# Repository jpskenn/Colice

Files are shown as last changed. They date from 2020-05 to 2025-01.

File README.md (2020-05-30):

# について / About
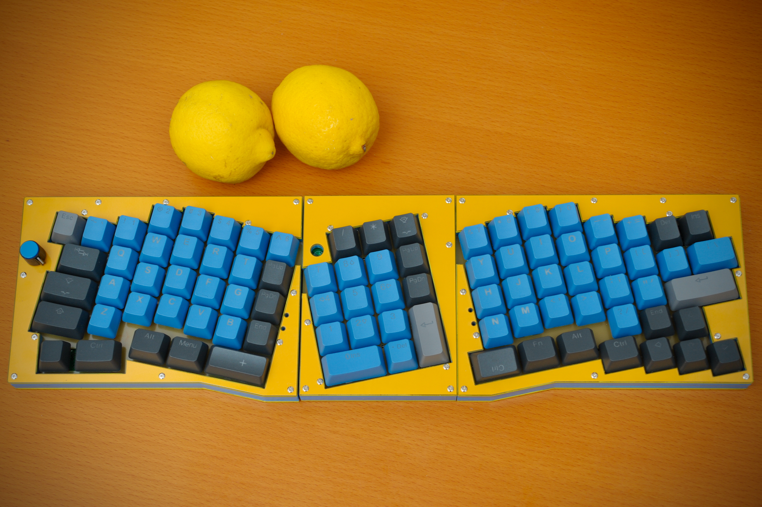
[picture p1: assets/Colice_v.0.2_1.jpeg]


Colice（コリス）

アリスのレイアウトに発想を得た、部位を組み合わせられるカラムスタッガー（列ずれ）配列の自作キーボード。
Self-made "Col"umnar stagger combinational moduler keyboard, inspired by Al"ice" layout.

## 特徴 / Features
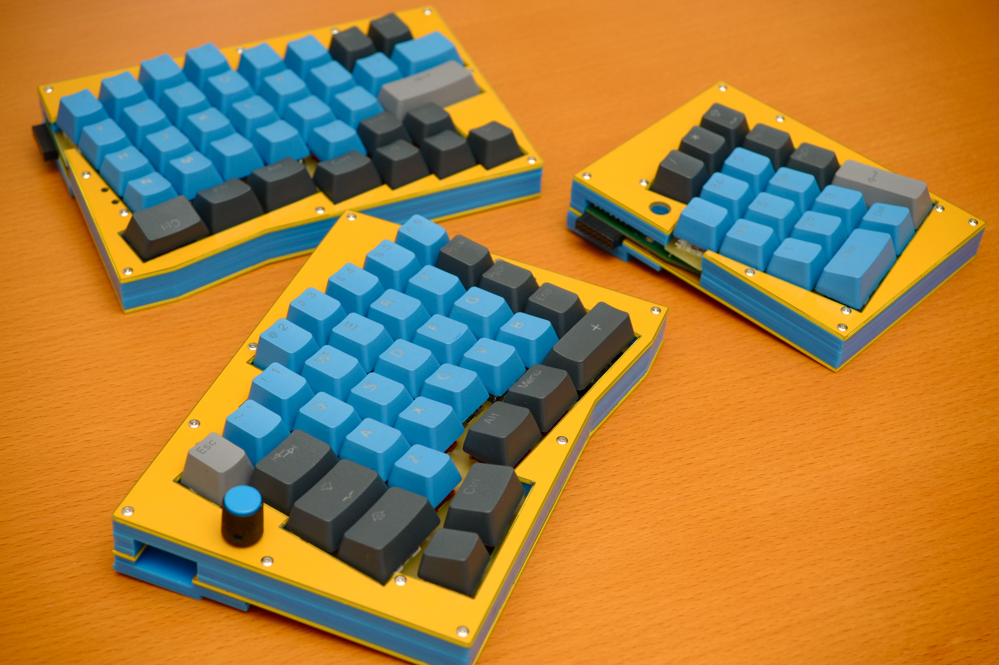
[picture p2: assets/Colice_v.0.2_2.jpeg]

- 一体型かつ分離型でレイアウトが変えられる
- トップマウント形式のケース
- ロータリーエンコーダを2個使用可能
- 総当たりマトリクス（2乗マトリクス）を採用
Pro Micro 1個で全てを制御
- I2C用のピンは未使用
- LEDチョットダケ光る
- 本来のケース外形はもっと丸い感じでかわいい
発注時ミスで、v.0.2は四角い外形になっている

## キー配列 / Layout

## 写真

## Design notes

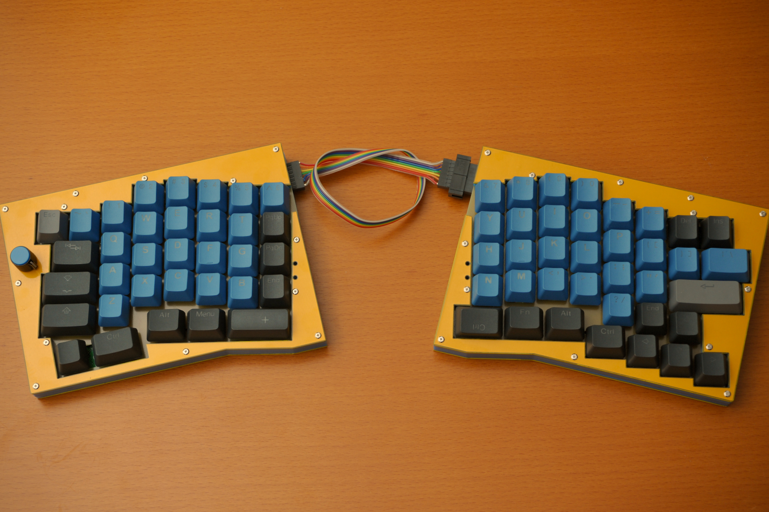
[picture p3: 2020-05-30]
assets/Colice_v.0.2_6.jpeg

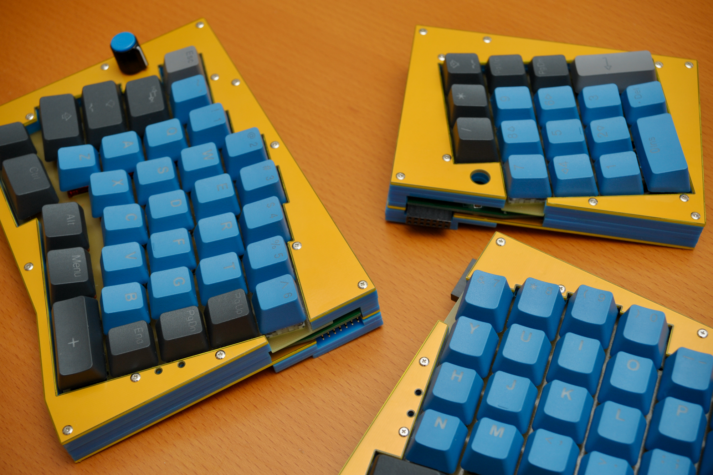
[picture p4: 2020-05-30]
assets/Colice_v.0.2_8.jpeg

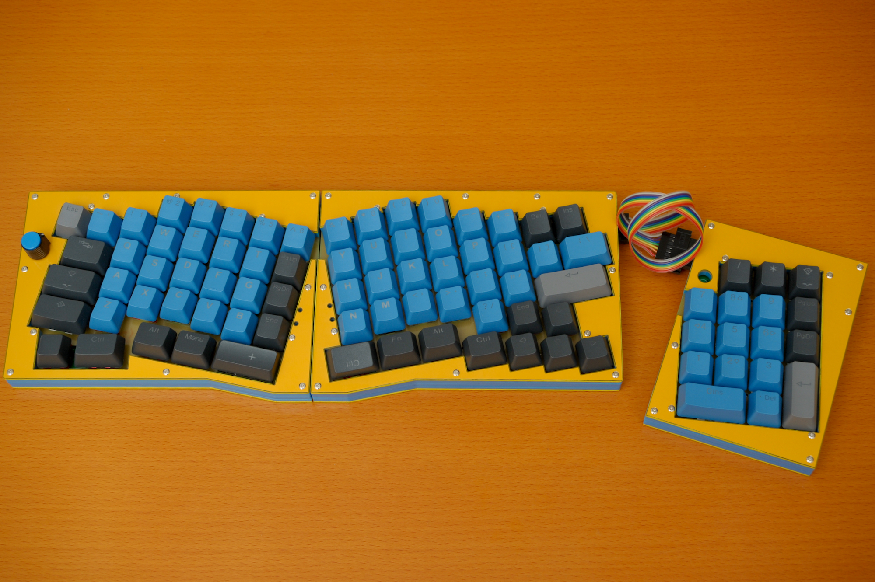
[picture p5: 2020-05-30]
assets/Colice_v.0.2_4.jpeg

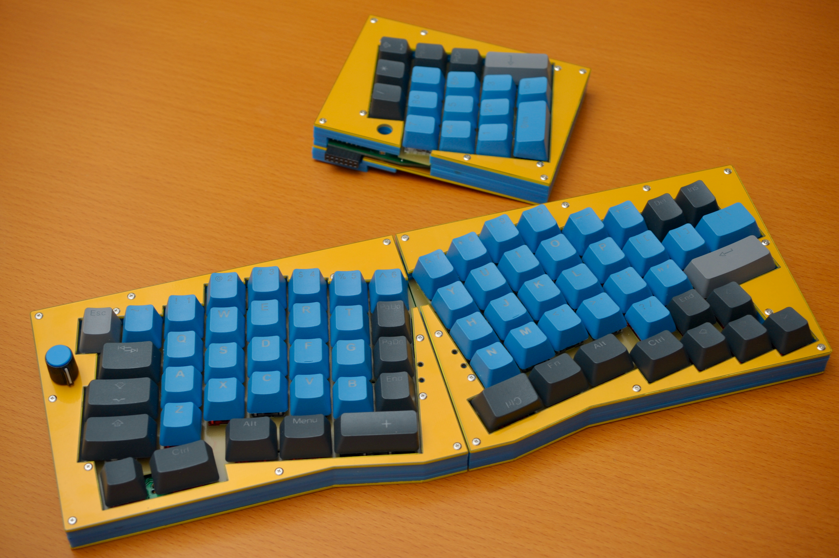
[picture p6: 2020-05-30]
assets/Colice_v.0.2_3.jpeg

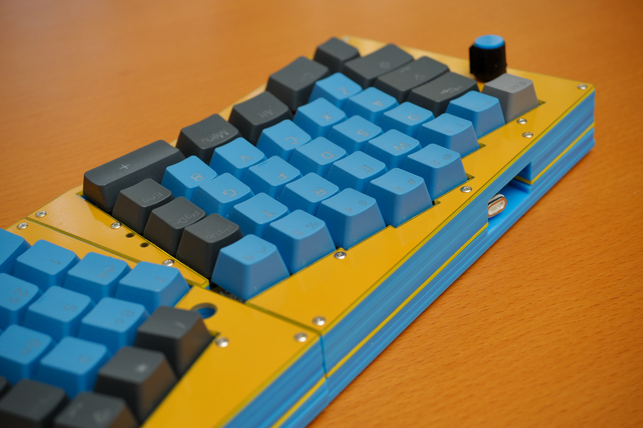
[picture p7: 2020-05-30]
assets/Colice_v.0.2_10.jpeg

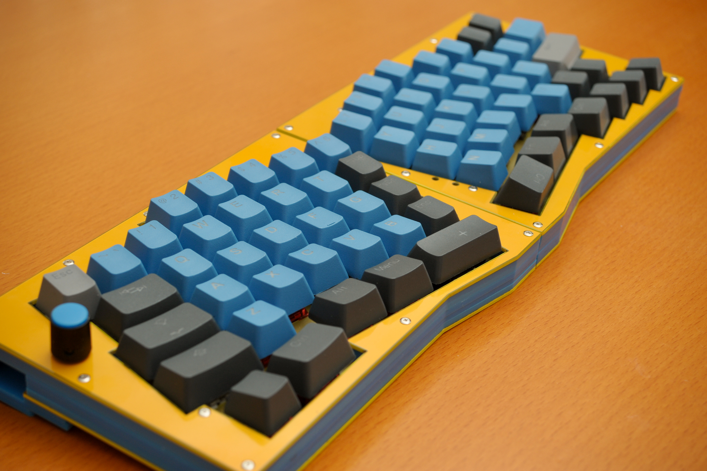
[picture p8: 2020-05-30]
assets/Colice_v.0.2_7.jpeg

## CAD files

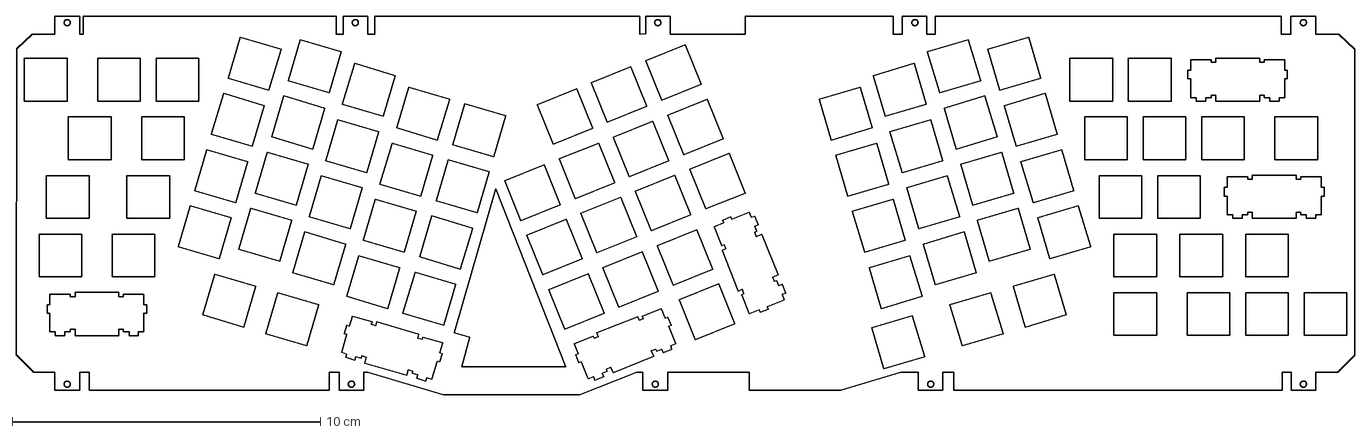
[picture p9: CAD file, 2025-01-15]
Case : Plate/キープレートPCB/Colice_20200219 v4.dxf
43.4 x 12.3 cm

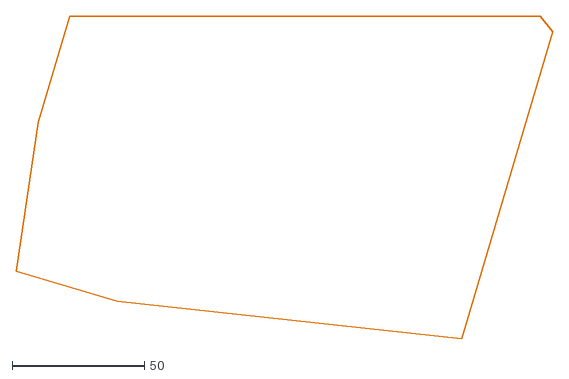
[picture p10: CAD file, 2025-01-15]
PCB/Colice_rev.0.1/board_outline.dxf
202.4 x 121.9

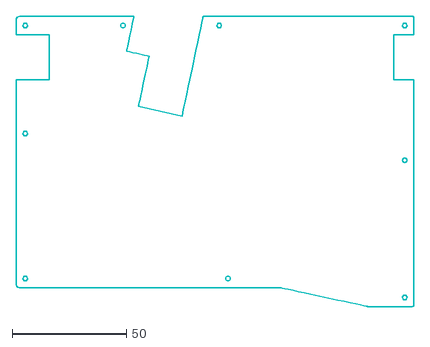
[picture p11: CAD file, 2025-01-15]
PCB_Bottom/v.0.2/LR-bottom-v02/outline.dxf
174.1 x 127.0

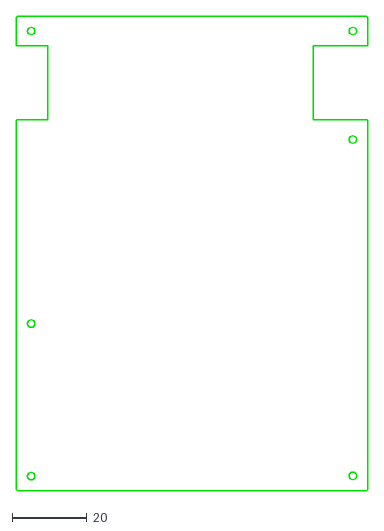
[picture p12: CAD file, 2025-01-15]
PCB_Bottom/v.0.2/N-bottom-v02/outline.dxf
94.1 x 127.0

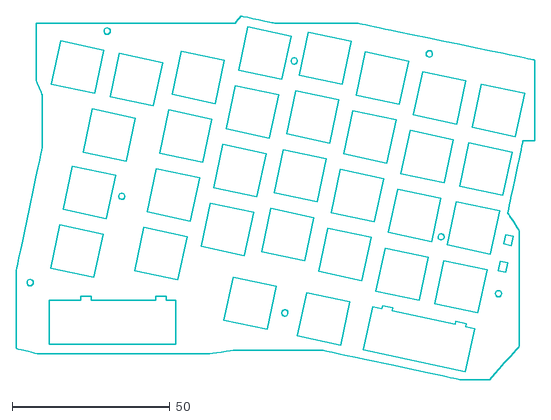
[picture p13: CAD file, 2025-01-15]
PCB_Keyplate/v.0.2/L-key-v02/outline.dxf
164.3 x 115.4

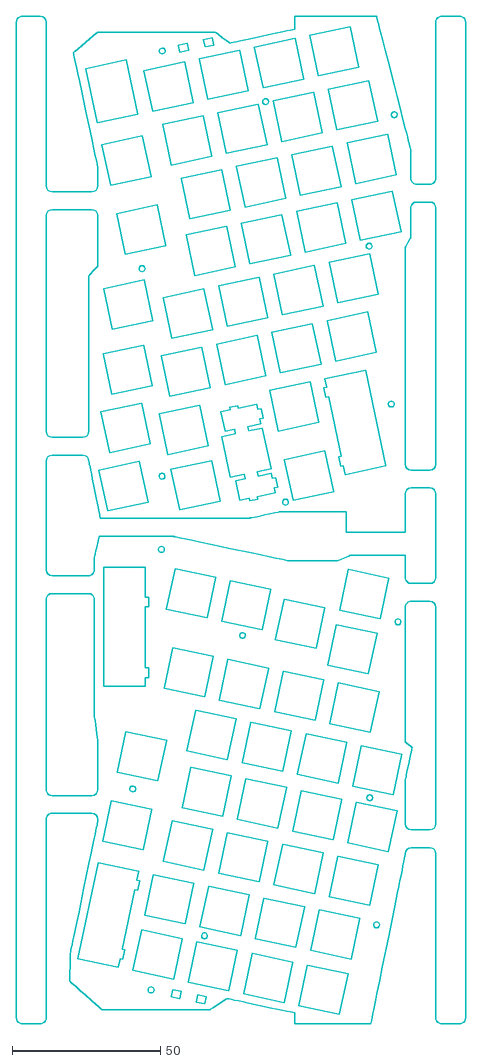
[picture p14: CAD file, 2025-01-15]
PCB_Keyplate/v.0.2/LR-key-v02/L+R_key.dxf
151.4 x 339.7

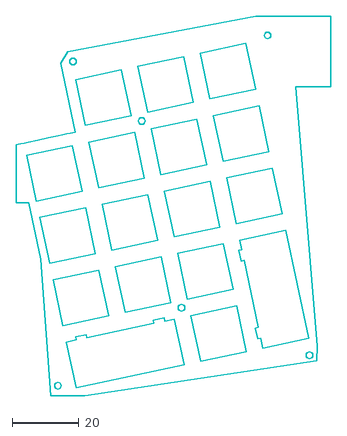
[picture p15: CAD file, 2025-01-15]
PCB_Keyplate/v.0.2/N-key-v02/outline.dxf
94.1 x 113.6

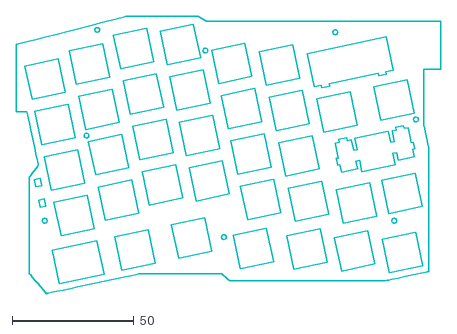
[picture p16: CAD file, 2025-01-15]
PCB_Keyplate/v.0.2/R-key-v02/outline.dxf
174.1 x 113.8

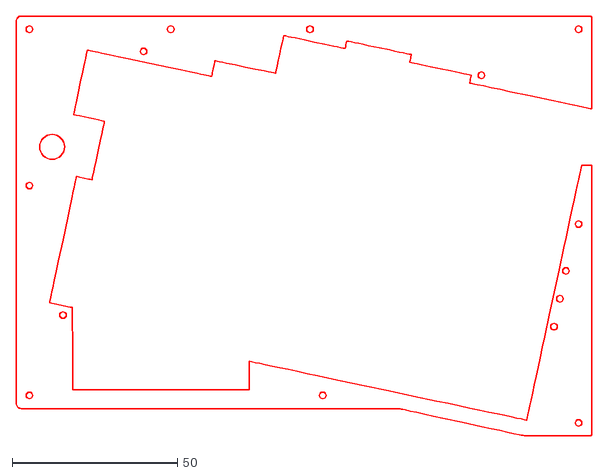
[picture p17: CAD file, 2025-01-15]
PCB_TopFrame/v.0.2/L-top-v02/outline.dxf
174.1 x 127.0

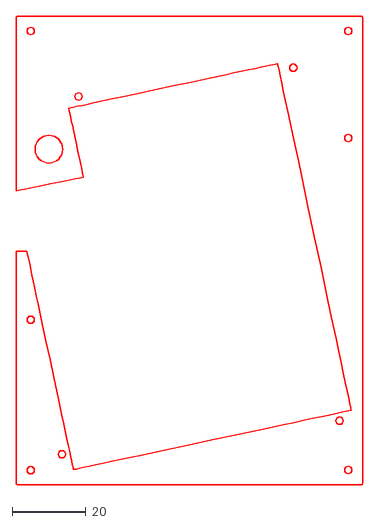
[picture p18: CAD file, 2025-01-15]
PCB_TopFrame/v.0.2/N-top-v02/outline.dxf
94.1 x 127.0

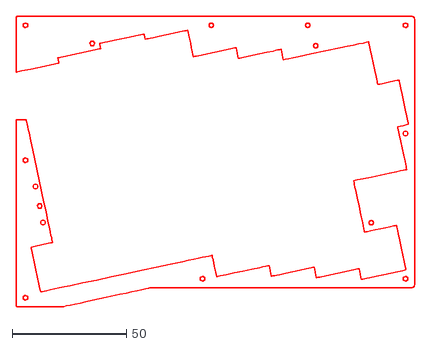
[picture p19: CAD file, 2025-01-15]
PCB_TopFrame/v.0.2/R-top-v02/outline.dxf
174.1 x 127.0

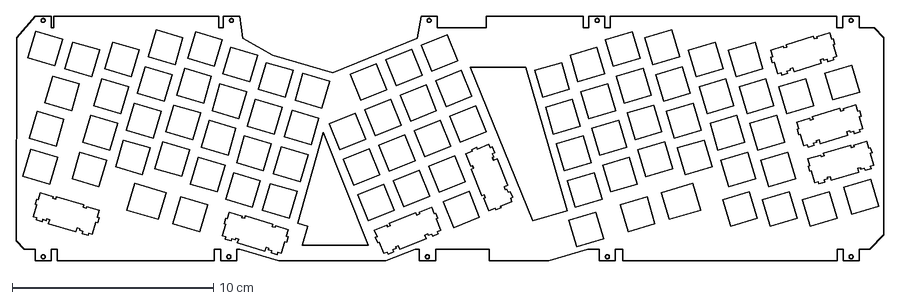
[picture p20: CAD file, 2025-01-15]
Case : Plate/キープレートPCB/Colice_PCB_Plate_v0.2 v1.dxf
43.1 x 12.1 cm

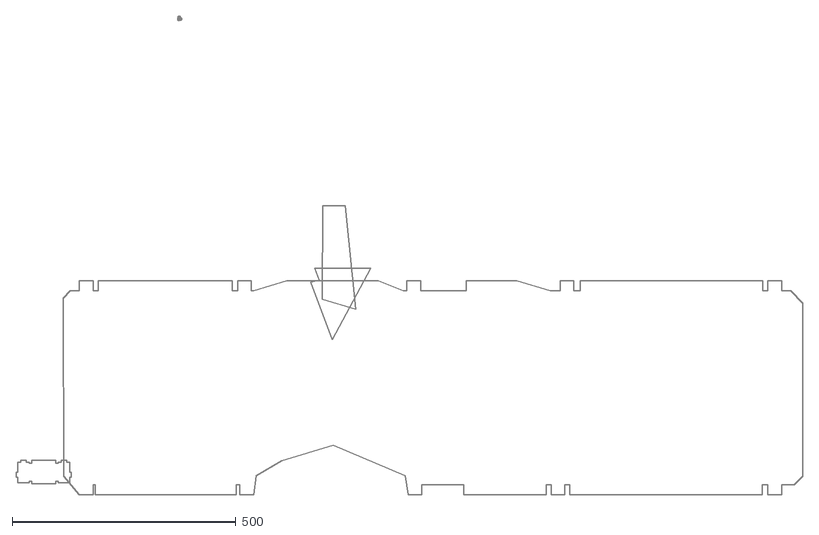
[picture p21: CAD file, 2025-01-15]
Case : Plate/キープレートPCB/case_plate_2_005_inkscape.dxf
1756.6 x 1069.9

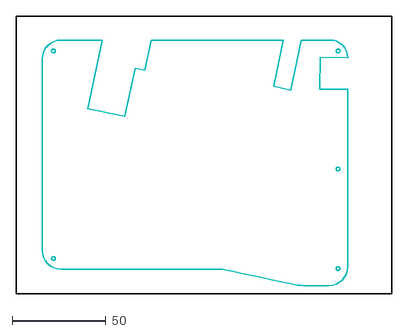
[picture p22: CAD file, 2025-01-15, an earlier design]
PCB_Bottom/v.0.1/left_bottom2.dxf
199.8 x 147.9

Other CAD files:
PCB_Keyplate/v.0.1/left_keyplate2.dxf
PCB_MidFrame/v.0.1/left_mid.dxf
PCB_TopFrame/v.0.1/left_top2.dxf
PCB_Bottom/v.0.1/left_bottom.dxf
PCB_Keyplate/v.0.1/left_keyplate.dxf
PCB_TopFrame/v.0.1/left_top.dxf
PCB_TopFrame/v.0.1/left_top3.dxf

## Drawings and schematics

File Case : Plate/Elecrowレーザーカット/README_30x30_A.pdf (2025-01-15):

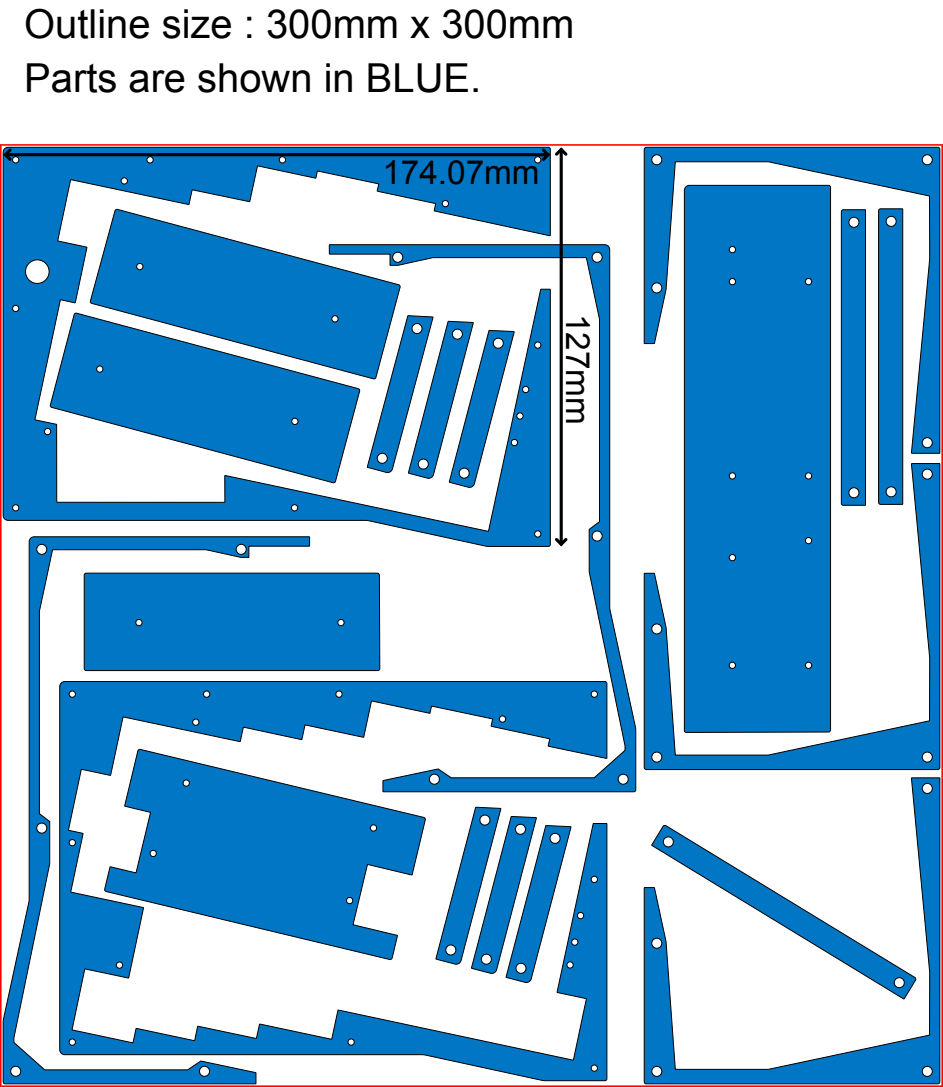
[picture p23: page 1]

Outline size : 300mm x 300mm
Parts are shown in BLUE.

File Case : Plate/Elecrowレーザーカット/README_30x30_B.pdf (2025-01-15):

# 46.5mm 174.07mm

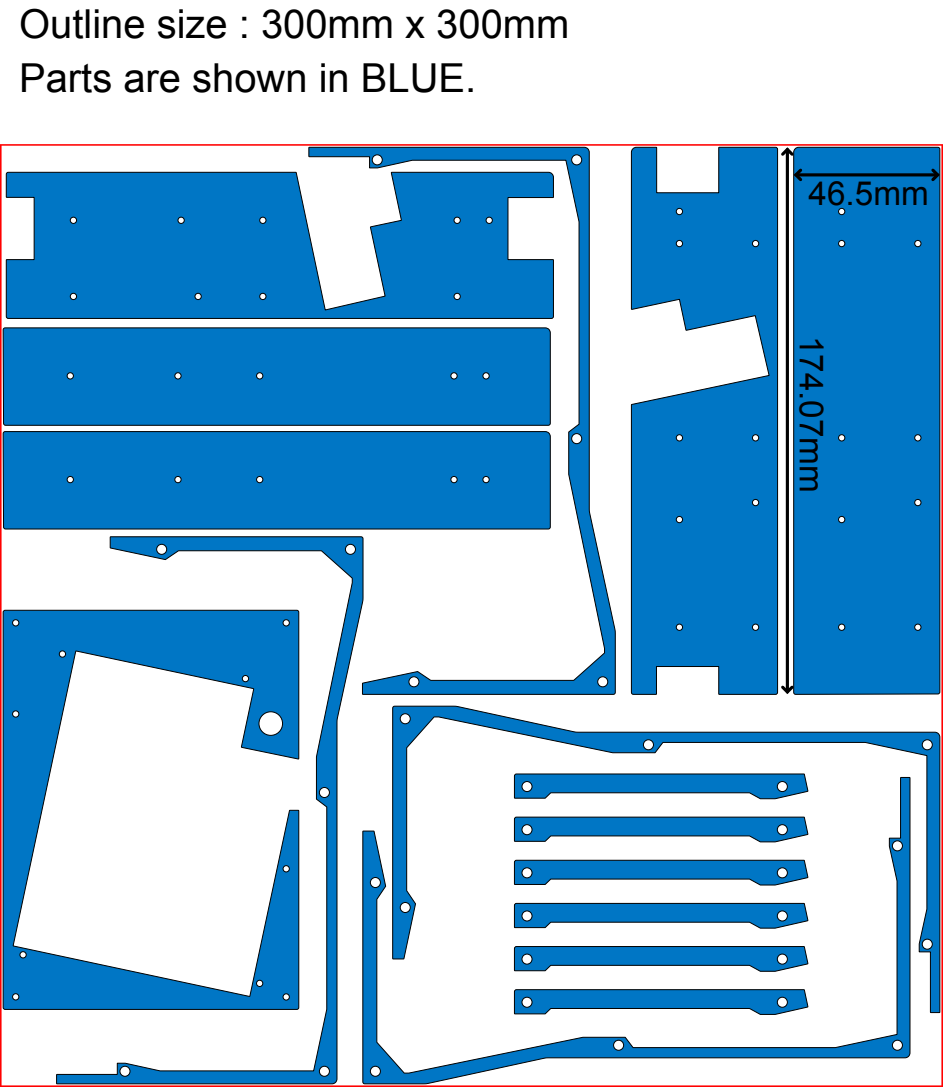
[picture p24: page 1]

Outline size : 300mm x 300mm
Parts are shown in BLUE.

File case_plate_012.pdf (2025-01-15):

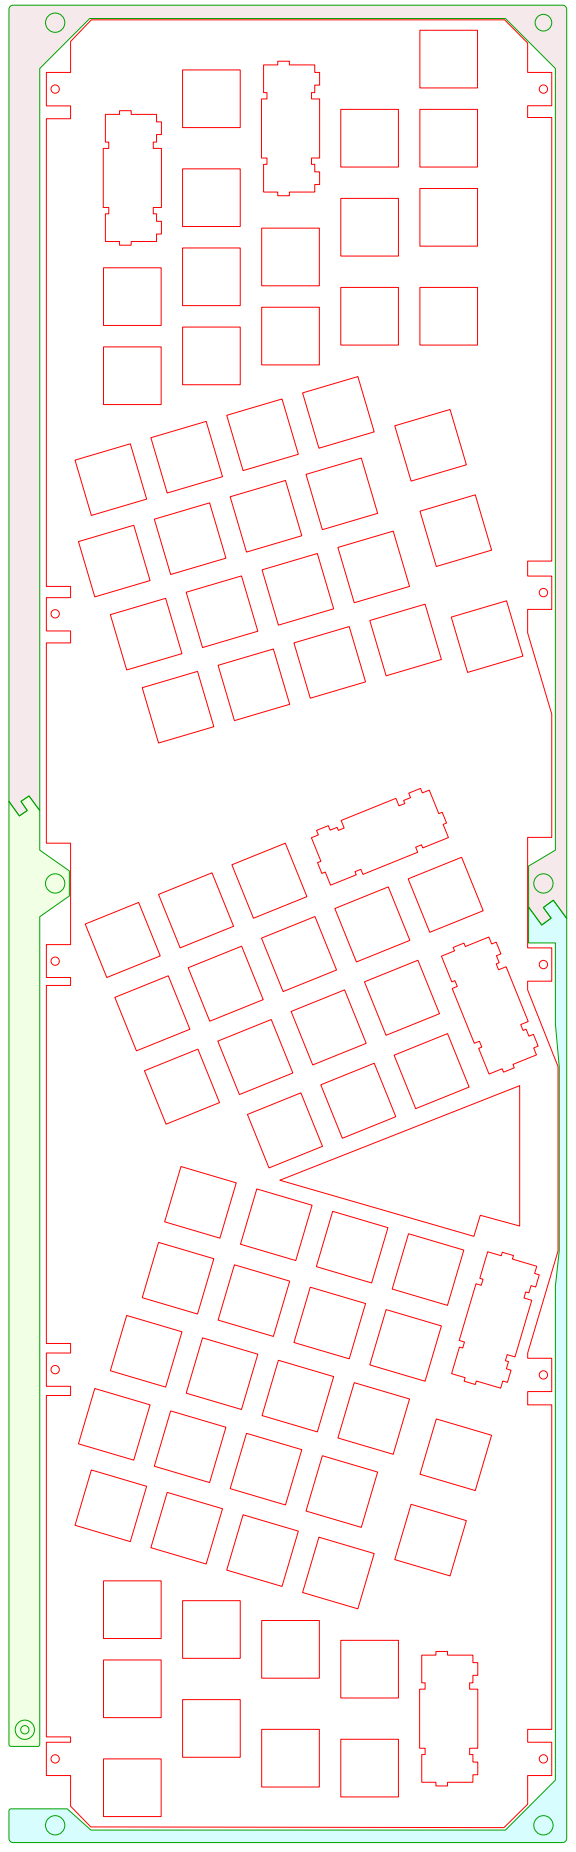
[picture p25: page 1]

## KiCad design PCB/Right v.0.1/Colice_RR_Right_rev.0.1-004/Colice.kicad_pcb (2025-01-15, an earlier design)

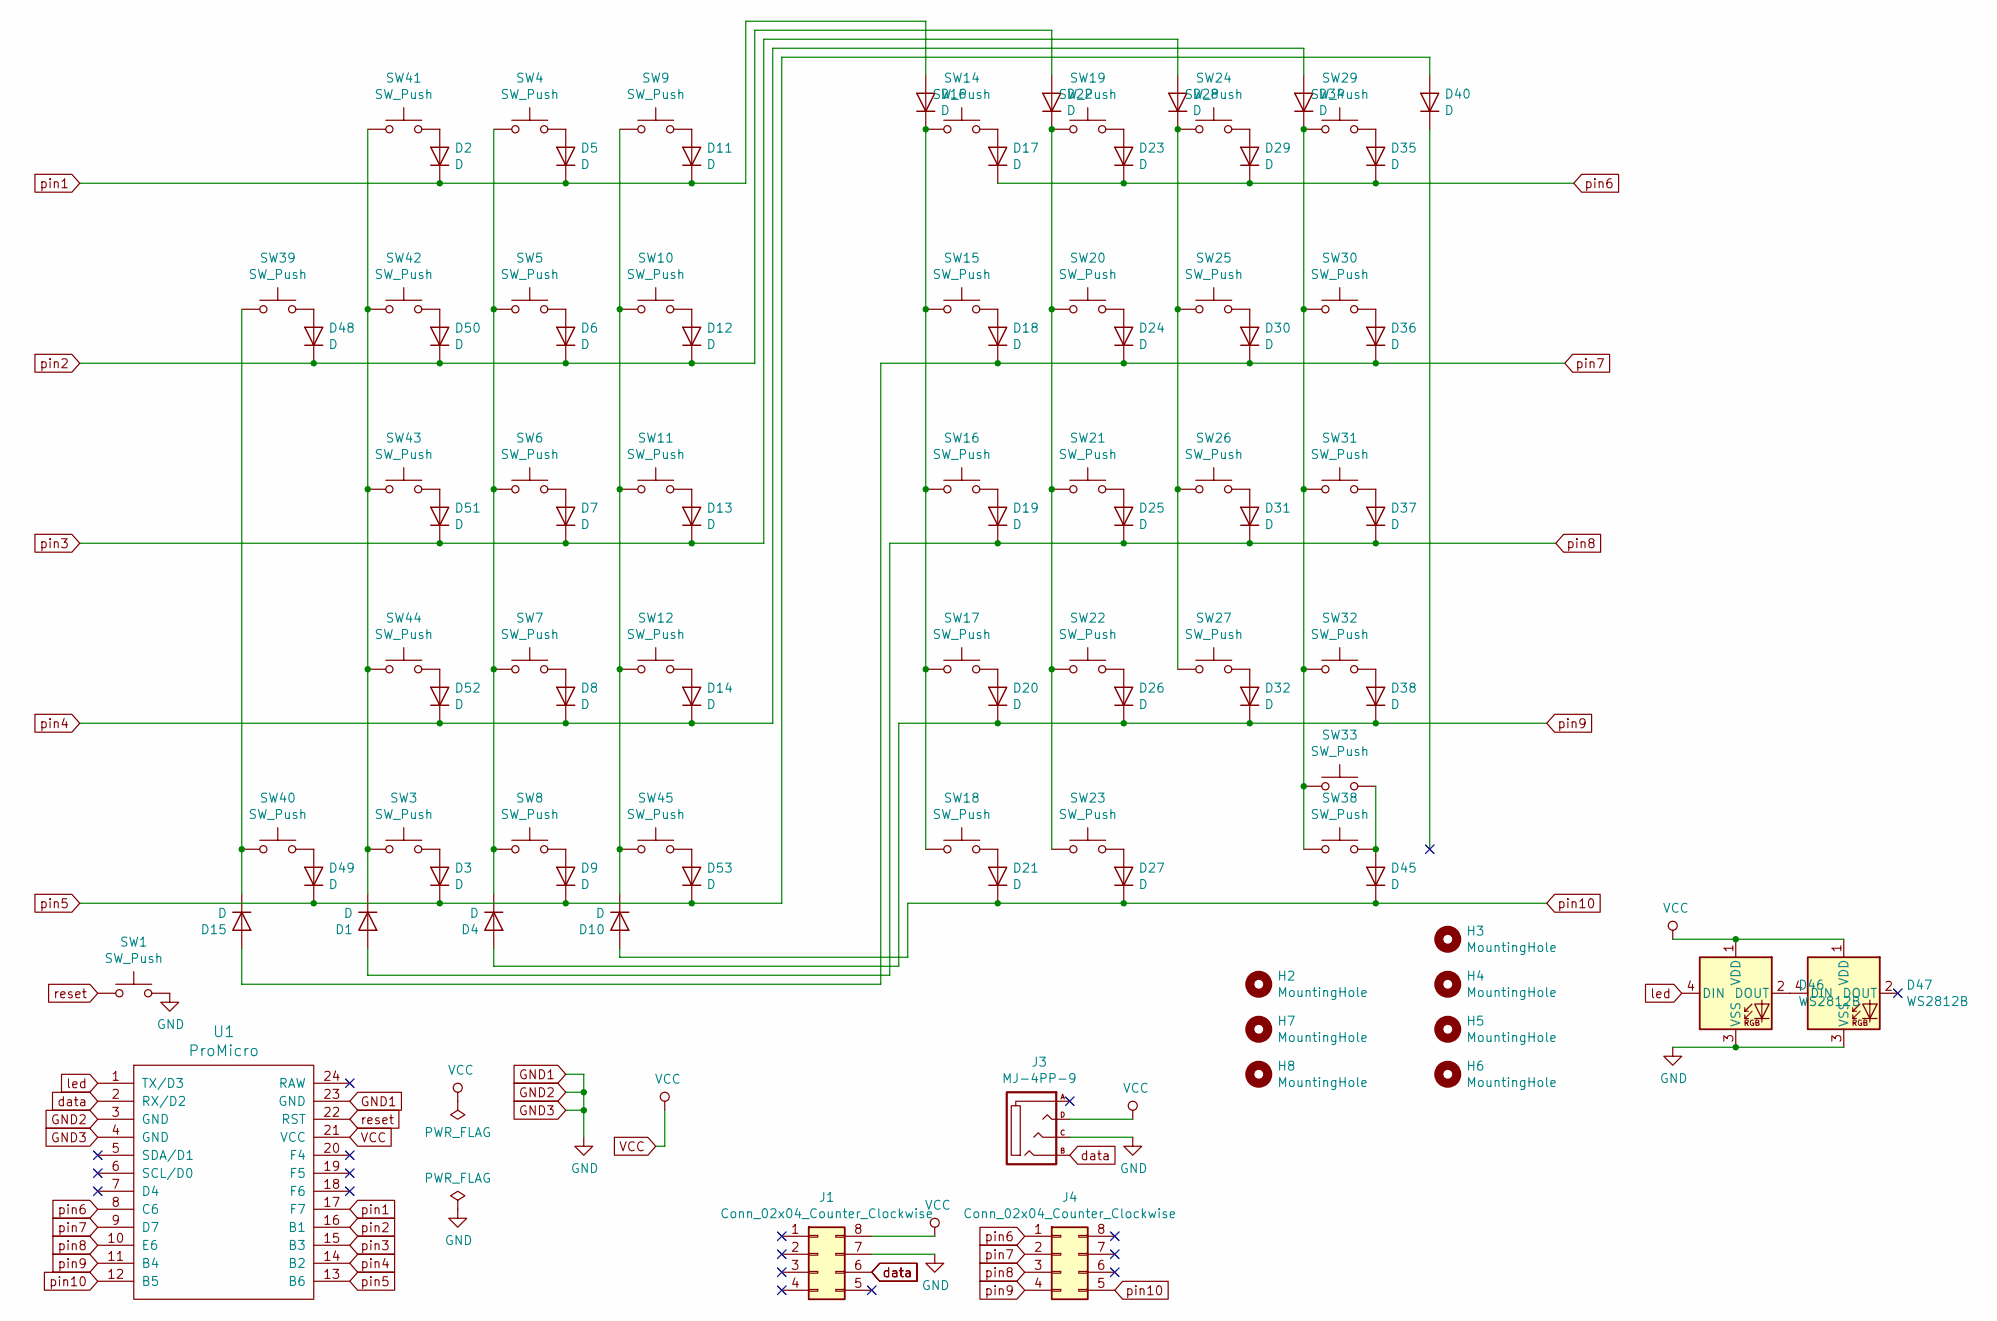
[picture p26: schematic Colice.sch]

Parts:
D1, D2, D3, D4, D5, D6, D7, D8, D9, D10, D11, D12, D13, D14, D15, D16, D17, D18, D19, D20, D21, D22, D23, D24, D25, D26, D27, D28, D29, D30, D31, D32, D34, D35, D36, D37, D38, D40, D45, D48, D49, D50, D51, D52, D53: D; D3_TH_SMD
D46, D47: WS2812B; LED_WS2812B_PLCC4_5.0x5.0mm_P3.2mm
H2: MountingHole; CherryMX_MidHeight_Choc_Hotswap_2U_Outline
H3, H4, H5, H6: MountingHole; MountingHole_2.2mm_M2_Pad_Via
H7, H8: MountingHole; CherryMX_MidHeight_Choc_Hotswap_2.25U_Outline
J1: Conn_02x04_Counter_Clockwise; PinHeader_2x04_P2.54mm_Horizontal
J3: MJ-4PP-9
J4: Conn_02x04_Counter_Clockwise; PinSocket_2x04_P2.54mm_Horizontal
SW1: SW_Push; ResetSW
SW3, SW6, SW7, SW8, SW9, SW10, SW11, SW12, SW14, SW15, SW16, SW17, SW18, SW19, SW20, SW21, SW22, SW23, SW24, SW25, SW26, SW27, SW29, SW30, SW31, SW32, SW33, SW38, SW39, SW40, SW41, SW42, SW43, SW44, SW45: SW_Push; CherryMX_Hotswap_v2
SW4, SW5: SW_Push; SW_Cherry_MX1A_1.00u_PCB
U1: ProMicro; ArduinoProMicro

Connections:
GND1: D46.3 (VSS), D47.3 (VSS), J1.7, J3.C, SW1.2, U1.3 (GND), U1.4 (GND), U1.23 (GND)
unnamed: D1.1 (K), SW3.1, SW41.1, SW42.1, SW43.1, SW44.1
unnamed: D2.2 (A), SW41.2
unnamed: D3.2 (A), SW3.2
unnamed: D4.1 (K), SW4.1, SW5.1, SW6.1, SW7.1, SW8.1
unnamed: D5.2 (A), SW4.2
unnamed: D6.2 (A), SW5.2
unnamed: D7.2 (A), SW6.2
unnamed: D8.2 (A), SW7.2
unnamed: D9.2 (A), SW8.2
unnamed: D10.1 (K), SW9.1, SW10.1, SW11.1, SW12.1, SW45.1
unnamed: D11.2 (A), SW9.2
unnamed: D12.2 (A), SW10.2
unnamed: D13.2 (A), SW11.2
unnamed: D14.2 (A), SW12.2
unnamed: D15.1 (K), SW39.1, SW40.1
unnamed: D16.1 (K), SW14.1, SW15.1, SW16.1, SW17.1, SW18.1
unnamed: D17.2 (A), SW14.2
unnamed: D18.2 (A), SW15.2
unnamed: D19.2 (A), SW16.2
unnamed: D20.2 (A), SW17.2
unnamed: D21.2 (A), SW18.2
unnamed: D22.1 (K), SW19.1, SW20.1, SW21.1, SW22.1, SW23.1
unnamed: D23.2 (A), SW19.2
unnamed: D24.2 (A), SW20.2
unnamed: D25.2 (A), SW21.2
unnamed: D26.2 (A), SW22.2
unnamed: D27.2 (A), SW23.2
unnamed: D28.1 (K), SW24.1, SW25.1, SW26.1, SW27.1
unnamed: D29.2 (A), SW24.2
unnamed: D30.2 (A), SW25.2
unnamed: D31.2 (A), SW26.2
unnamed: D32.2 (A), SW27.2
unnamed: D34.1 (K), SW29.1, SW30.1, SW31.1, SW32.1, SW33.1, SW38.1
unnamed: D35.2 (A), SW29.2
unnamed: D36.2 (A), SW30.2
unnamed: D37.2 (A), SW31.2
unnamed: D38.2 (A), SW32.2
unnamed: D45.2 (A), SW33.2, SW38.2
unnamed: D46.2 (DOUT), D47.4 (DIN)
unnamed: D48.2 (A), SW39.2
unnamed: D49.2 (A), SW40.2
unnamed: D50.2 (A), SW42.2
unnamed: D51.2 (A), SW43.2
unnamed: D52.2 (A), SW44.2
unnamed: D53.2 (A), SW45.2
VCC: D46.1 (VDD), D47.1 (VDD), J1.8, J3.D, U1.21 (VCC)
data: J1.6, J3.B, U1.2 (RX/D2)
led: D46.4 (DIN), U1.1 (TX/D3)
pin1: D2.1 (K), D5.1 (K), D11.1 (K), D16.2 (A), U1.17 (F7)
pin2: D6.1 (K), D12.1 (K), D22.2 (A), D48.1 (K), D50.1 (K), U1.16 (B1)
pin3: D7.1 (K), D13.1 (K), D28.2 (A), D51.1 (K), U1.15 (B3)
pin4: D8.1 (K), D14.1 (K), D34.2 (A), D52.1 (K), U1.14 (B2)
pin5: D3.1 (K), D9.1 (K), D40.2 (A), D49.1 (K), D53.1 (K), U1.13 (B6)
pin6: D17.1 (K), D23.1 (K), D29.1 (K), D35.1 (K), J4.1, U1.8 (C6)
pin7: D15.2 (A), D18.1 (K), D24.1 (K), D30.1 (K), D36.1 (K), J4.2, U1.9 (D7)
pin8: D1.2 (A), D19.1 (K), D25.1 (K), D31.1 (K), D37.1 (K), J4.3, U1.10 (E6)
pin9: D4.2 (A), D20.1 (K), D26.1 (K), D32.1 (K), D38.1 (K), J4.4, U1.11 (B4)
pin10: D10.2 (A), D21.1 (K), D27.1 (K), D45.1 (K), J4.5, U1.12 (B5)
reset: SW1.1, U1.22 (RST)

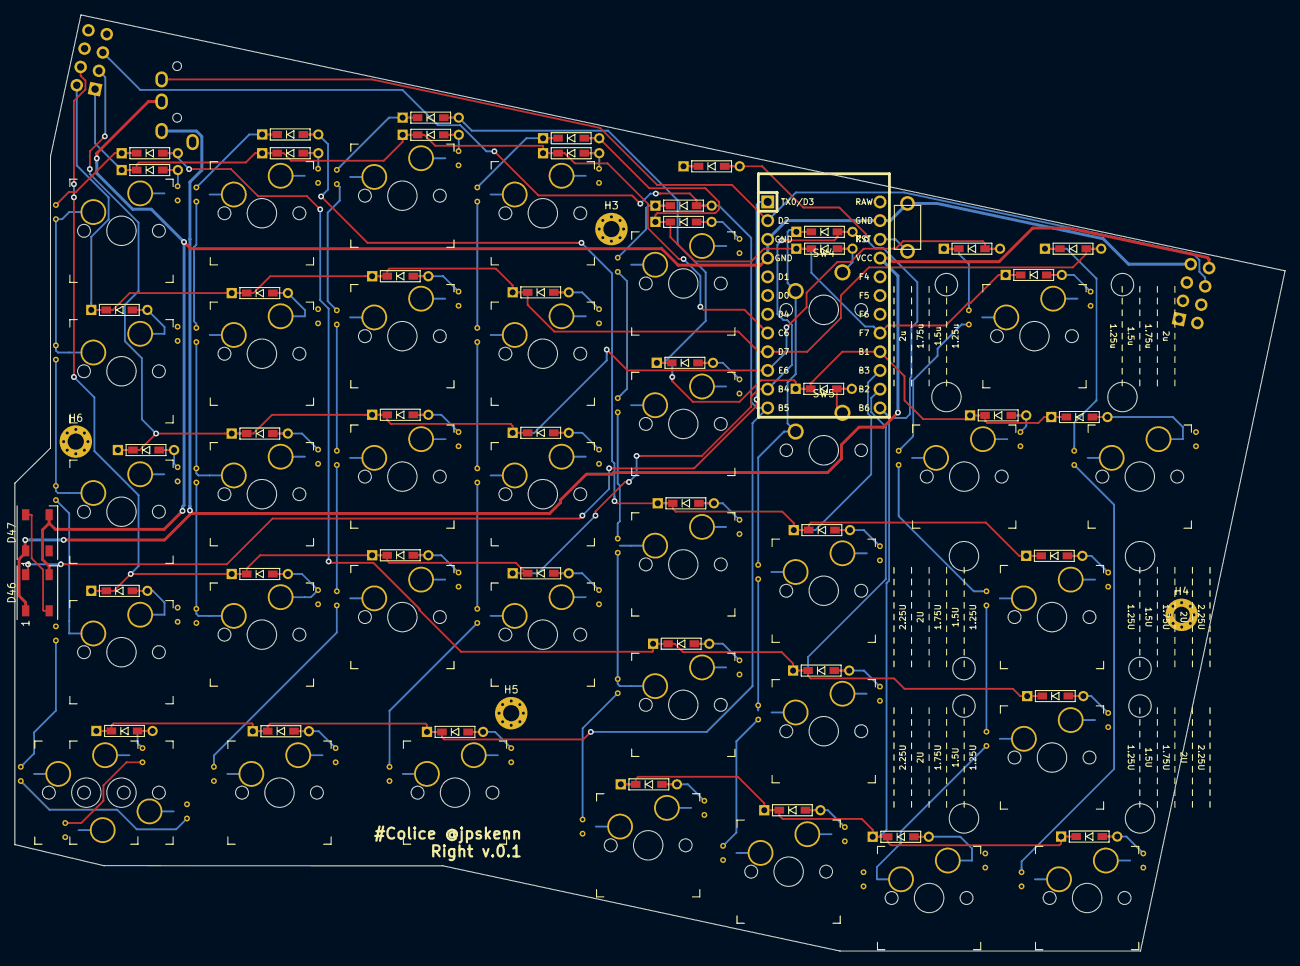
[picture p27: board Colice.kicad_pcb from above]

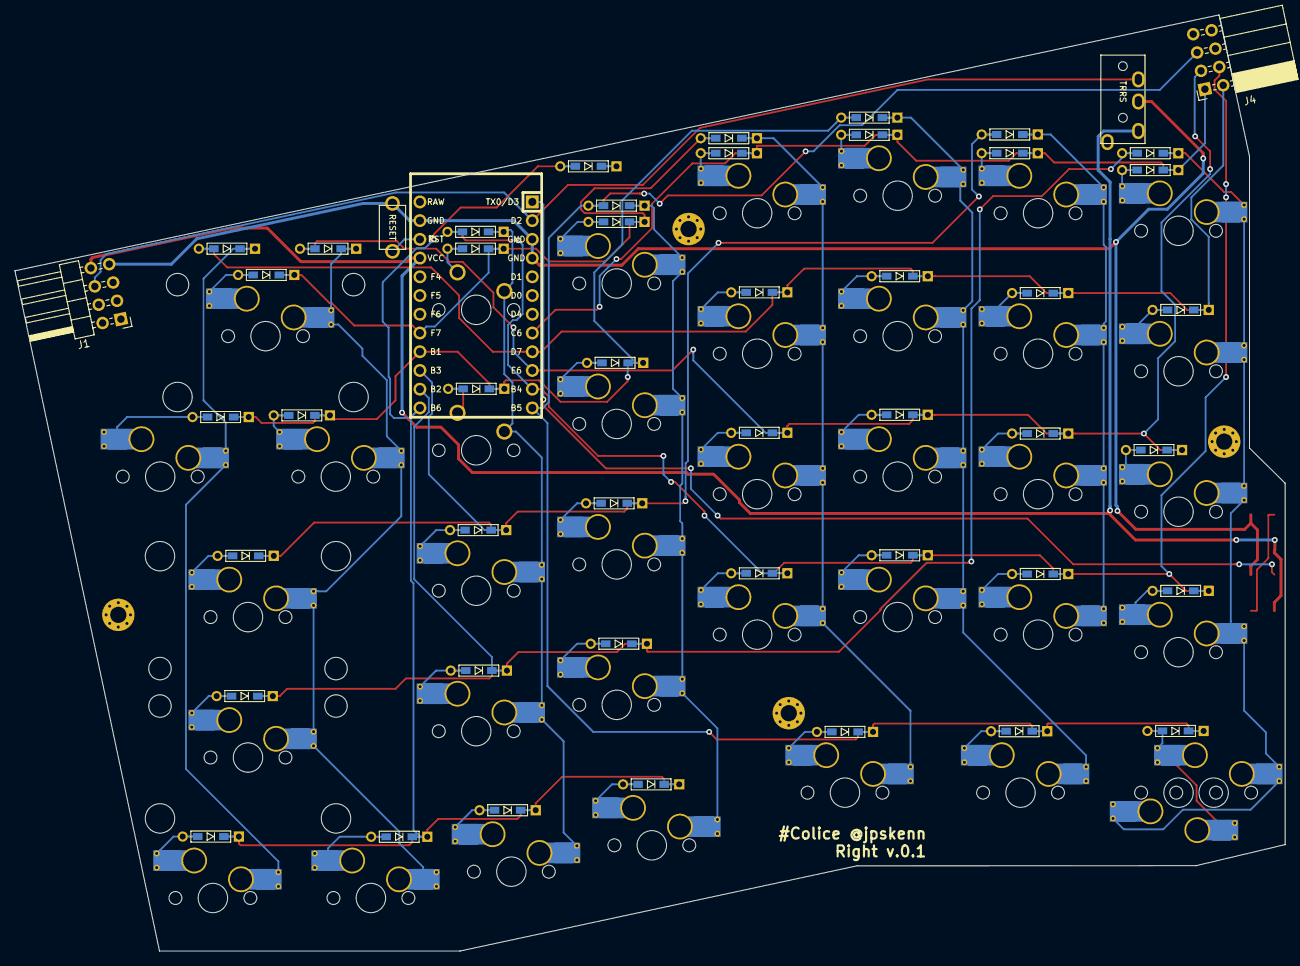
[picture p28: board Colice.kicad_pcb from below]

Board: 2 copper layers, 172.3 x 127.0 mm, 96 parts (5 on the bottom side), 60 nets.

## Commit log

2020-05-30 Add 写真素材追加
2020-05-30 Update 写真追加。特徴追記。
2020-05-30 Update 画像ファイル名変更
2025-01-15 ローカルデータをリポジトリへ配置
    [Colice 3.sch, Colice 4.sch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]
